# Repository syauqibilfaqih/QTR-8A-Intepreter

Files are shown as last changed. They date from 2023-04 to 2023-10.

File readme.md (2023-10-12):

# QTR-8A Interpreter 

This is the repository of QTR-8A Interpreter circuit that supports both digital data transmission through gpio pins and UART communication between master microcontroller and slave microcontroller, which is Arduino Nano, to read the QTR-8A sensor data. Use KiCad to open the schematic and board file, whereas use PlatformIO VS Code to open the code and build it.



To calibrate the line sensor, there are three ways to trigger the calibration mode:

1. By pressing button
2. By sending command "clib" via UART
3. By giving active signal to pin 12

Once the calibration mode is activated, move the sensors to get the black and white surface of the track. When it's done, the led indicators will show the correct reading state, where if the sensor read the black surface, the led will be turned on, otherwise it will be turned off.

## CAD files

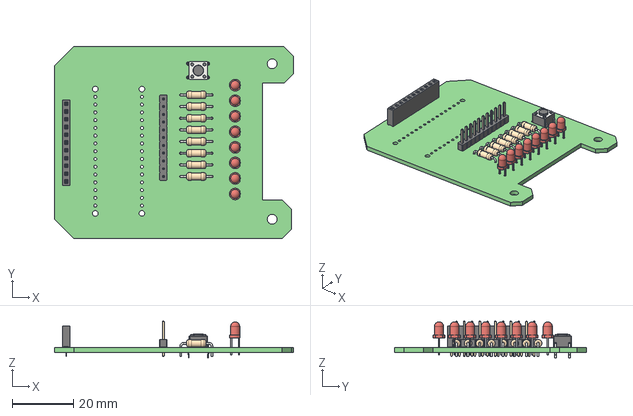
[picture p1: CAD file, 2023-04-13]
LineSensor/LineSensor.step
78.1 x 62.9 x 12.0 mm

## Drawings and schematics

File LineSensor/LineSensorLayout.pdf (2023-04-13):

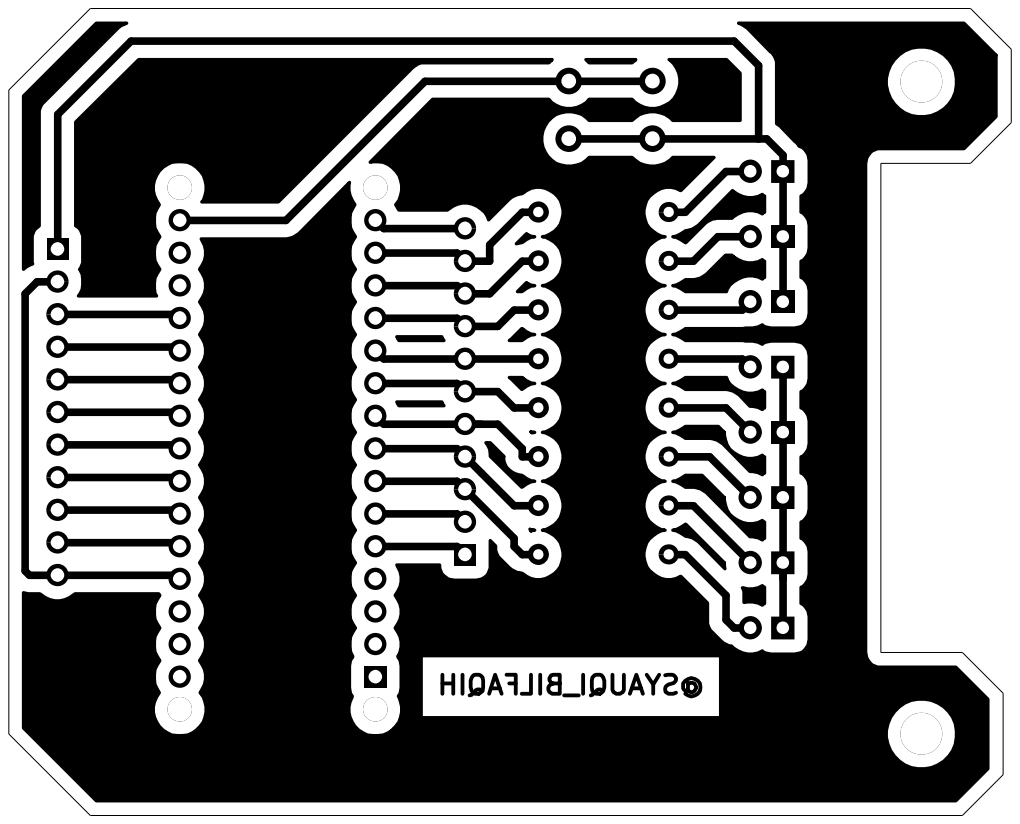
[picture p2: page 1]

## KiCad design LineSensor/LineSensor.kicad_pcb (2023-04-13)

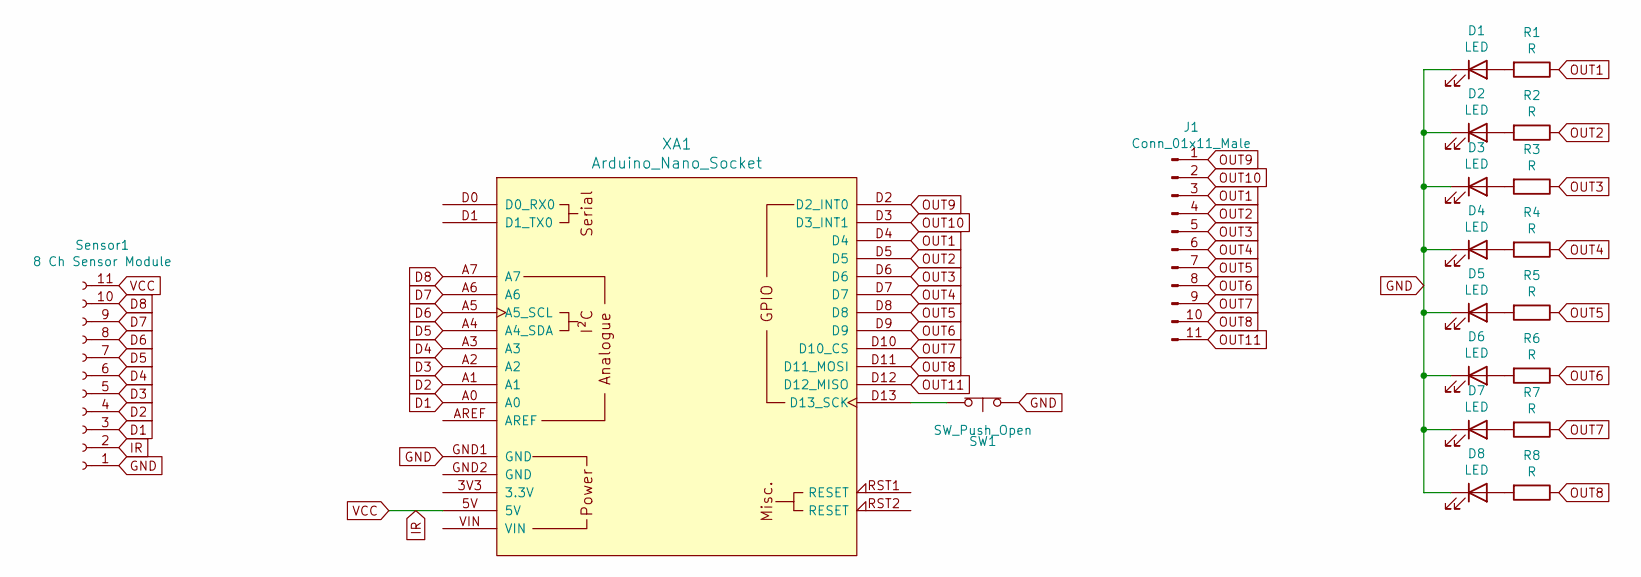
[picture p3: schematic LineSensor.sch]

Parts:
D1, D2, D3, D4, D5, D6, D7, D8: LED; LED_D3.0mm
J1: Conn_01x11_Male; PinHeader_1x11_P2.54mm_Vertical
R1, R2, R3, R4, R5, R6, R7, R8: R; R_Axial_DIN0207_L6.3mm_D2.5mm_P10.16mm_Horizontal
SW1: SW_Push_Open; SW_PUSH_6mm
Sensor1: 8 Ch Sensor Module; PinSocket_1x11_P2.54mm_Vertical
XA1: Arduino_Nano_Socket

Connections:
D1: Sensor1.3, XA1.A0
D2: Sensor1.4, XA1.A1
D3: Sensor1.5, XA1.A2
D4: Sensor1.6, XA1.A3
D5: Sensor1.7, XA1.A4 (A4_SDA)
D6: Sensor1.8, XA1.A5 (A5_SCL)
D7: Sensor1.9, XA1.A6
D8: Sensor1.10, XA1.A7
GND: D1.1 (K), D2.1 (K), D3.1 (K), D4.1 (K), D5.1 (K), D6.1 (K), D7.1 (K), D8.1 (K), SW1.1 (A), Sensor1.1, XA1.GND1 (GND)
IR: Sensor1.2, Sensor1.11, XA1.5V
unnamed: D1.2 (A), R1.2
unnamed: D2.2 (A), R2.2
unnamed: D3.2 (A), R3.2
unnamed: D4.2 (A), R4.2
unnamed: D5.2 (A), R5.2
unnamed: D6.2 (A), R6.2
unnamed: D7.2 (A), R7.2
unnamed: D8.2 (A), R8.2
unnamed: SW1.2 (B), XA1.D13 (D13_SCK)
OUT1: J1.3, R1.1, XA1.D4
OUT2: J1.4, R2.1, XA1.D5
OUT3: J1.5, R3.1, XA1.D6
OUT4: J1.6, R4.1, XA1.D7
OUT5: J1.7, R5.1, XA1.D8
OUT6: J1.8, R6.1, XA1.D9
OUT7: J1.9, R7.1, XA1.D10 (D10_CS)
OUT8: J1.10, R8.1, XA1.D11 (D11_MOSI)
OUT9: J1.1, XA1.D2 (D2_INT0)
OUT10: J1.2, XA1.D3 (D3_INT1)
OUT11: J1.11, XA1.D12 (D12_MISO)

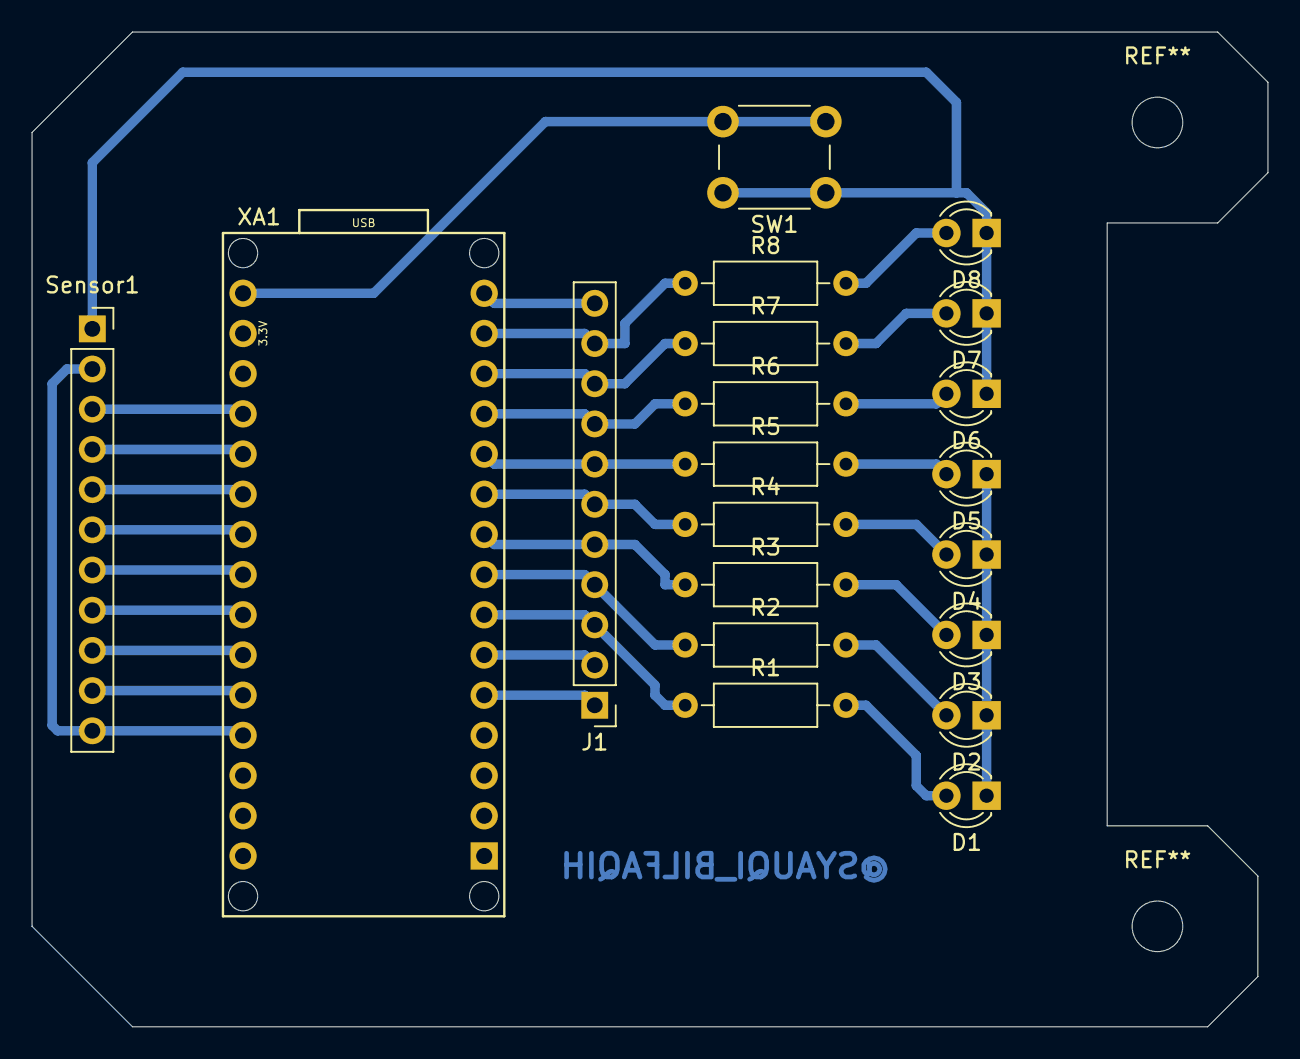
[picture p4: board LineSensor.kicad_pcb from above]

Board: 2 copper layers, 78.1 x 62.9 mm, 20 parts (0 on the bottom side), 30 nets.

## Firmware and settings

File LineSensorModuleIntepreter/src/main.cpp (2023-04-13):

#include <Arduino.h>
#include <QTRSensors.h>

// This example is designed for use with six analog QTR sensors. These
// reflectance sensors should be connected to analog pins A0 to A5. The
// sensors' emitter control pin (CTRL or LEDON) can optionally be connected to
// digital pin 2, or you can leave it disconnected and remove the call to
// setEmitterPin().
//
// The setup phase of this example calibrates the sensors for ten seconds and
// turns on the Arduino's LED (usually on pin 13) while calibration is going
// on. During this phase, you should expose each reflectance sensor to the
// lightest and darkest readings they will encounter. For example, if you are
// making a line follower, you should slide the sensors across the line during
// the calibration phase so that each sensor can get a reading of how dark the
// line is and how light the ground is. Improper calibration will result in
// poor readings.
//
// The main loop of the example reads the calibrated sensor values and uses
// them to estimate the position of a line. You can test this by taping a piece
// of 3/4" black electrical tape to a piece of white paper and sliding the
// sensor across it. It prints the sensor values to the serial monitor as
// numbers from 0 (maximum reflectance) to 1000 (minimum reflectance) followed
// by the estimated location of the line as a number from 0 to 5000. 1000 means
// the line is directly under sensor 1, 2000 means directly under sensor 2,
// etc. 0 means the line is directly under sensor 0 or was last seen by sensor
// 0 before being lost. 5000 means the line is directly under sensor 5 or was
// last seen by sensor 5 before being lost.

QTRSensors qtr;

const uint8_t SensorCount = 8;
uint16_t sensorValues[SensorCount];
uint8_t sensorPos=0;

void setup()
{
  // configure the sensors
  qtr.setTypeAnalog();
  qtr.setSensorPins((const uint8_t[]){A0, A1, A2, A3, A4, A5, A6, A7}, SensorCount);

  delay(500);
  pinMode(4, OUTPUT);
  pinMode(5, OUTPUT);
  pinMode(6, OUTPUT);
  pinMode(7, OUTPUT);
  pinMode(8, OUTPUT);
  pinMode(9, OUTPUT);
  pinMode(10, OUTPUT);
  pinMode(11, OUTPUT);
  pinMode(12,INPUT);
  Serial.begin(9600);

      // analogRead() takes about 0.1 ms on an AVR.
    // 0.1 ms per sensor * 4 samples per sensor read (default) * 6 sensors
    // * 10 reads per calibrate() call = ~24 ms per calibrate() call.
    // Call calibrate() 400 times to make calibration take about 10 seconds.
    digitalWrite(5, HIGH); // turn on Arduino's LED to indicate we are in calibration mode

    for (uint16_t i = 0; i < 400; i++)
    {
      qtr.calibrate();
    }
    digitalWrite(5, LOW); // turn off Arduino's LED to indicate we are through with calibration

    // print the calibration minimum values measured when emitters were on
    for (uint8_t i = 0; i < SensorCount; i++)
    {
      Serial.print(qtr.calibrationOn.minimum[i]);
      Serial.print(' ');
    }
    Serial.println();

    // print the calibration maximum values measured when emitters were on
    for (uint8_t i = 0; i < SensorCount; i++)
    {
      Serial.print(qtr.calibrationOn.maximum[i]);
      Serial.print(' ');
    }
    Serial.println();
    Serial.println();
    delay(1000);
    
}

void loop()
{
  uint8_t kondisiButton=digitalRead(12);
  String calibState = "no";
  //Serial.println(kondisiButton);
  while(Serial.available()>0)
  {
    calibState=Serial.readString();
    Serial.print(calibState);
    calibState.trim();
  }
  if(!kondisiButton || calibState == "clib")
  {
        // analogRead() takes about 0.1 ms on an AVR.
    // 0.1 ms per sensor * 4 samples per sensor read (default) * 6 sensors
    // * 10 reads per calibrate() call = ~24 ms per calibrate() call.
    // Call calibrate() 400 times to make calibration take about 10 seconds.
    digitalWrite(5, HIGH); // turn on Arduino's LED to indicate we are in calibration mode

    for (uint16_t i = 0; i < 400; i++)
    {
      qtr.calibrate();
    }
    digitalWrite(5, LOW); // turn off Arduino's LED to indicate we are through with calibration

    // print the calibration minimum values measured when emitters were on
    for (uint8_t i = 0; i < SensorCount; i++)
    {
      Serial.print(qtr.calibrationOn.minimum[i]);
      Serial.print(' ');
    }
    Serial.println();

    // print the calibration maximum values measured when emitters were on
    for (uint8_t i = 0; i < SensorCount; i++)
    {
      Serial.print(qtr.calibrationOn.maximum[i]);
      Serial.print(' ');
    }
    Serial.println();
    Serial.println();
    delay(1000);
    calibState="no";
      
  }
 
    // read calibrated sensor values and obtain a measure of the line position
      // from 0 to 5000 (for a white line, use readLineWhite() instead)
      //uint16_t position = qtr.readLineBlack(sensorValues);
      qtr.readLineBlack(sensorValues);
      // print the sensor values as numbers from 0 to 1000, where 0 means maximum
      // reflectance and 1000 means minimum reflectance, followed by the line
      // position
      sensorPos=0;
      for (uint8_t i = 0; i < SensorCount; i++)
      {
        if(sensorValues[i]>800)
        {
          digitalWrite(abs(i-11),HIGH);
          sensorPos+=(1<<i);
        }
        else
        {
          digitalWrite(abs(i-11),LOW);
        }
      }
      for (uint8_t i = 0; i < SensorCount; i++)
      {
      // Serial.print(sensorValues[i]);
      // Serial.print('\t');
      }
      //Serial.println(sensorPos);
      Serial.println(sensorPos);
      delay(10);

  
}
